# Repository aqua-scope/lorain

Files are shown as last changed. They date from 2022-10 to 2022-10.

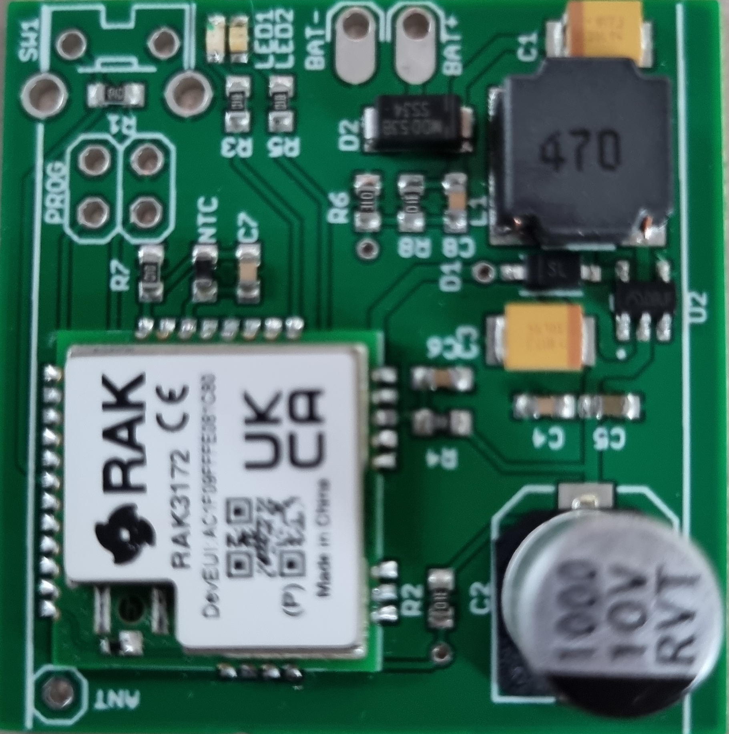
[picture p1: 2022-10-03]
img/lorain_pcba.jpg

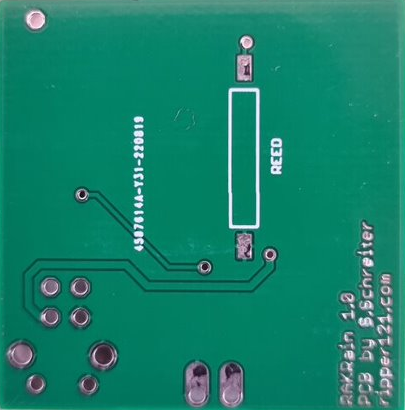
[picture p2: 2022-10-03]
img/lorain_pcb_back.png

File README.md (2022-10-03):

<h1> Lora Rain Sensor </h1>

<p>Lorain is an affordable LoraWAN rain sensor utilizing the RAK 3172 Lora Module that can be programmed using Arduino environment. </p>

<h2> Hardware</h2>

<p>There are multiple ways to acquire the hardware for the LoRain. The Aqua-Scope Webshop at <a href="https://shop.aqua-scope.com">shop.aqua-scope.com</a> offers different options depending on your willingness to spent own effort in exchange for money:
<ul>
<li>Complete product tested and ready to use</li>
<li>Kit with all needed components and need to solder some of the components and flash the firmware. 
The kit includes a PCBA almost fully populated</li>
<li>The plain enclosure of the device. You need to order the PCB / <a href="img/lorain_pcba.jpg">PCBA</a>, purchase and solder all components and flash the firmware. The 'How-To' below assumes this option.</li>
</ul>
<p> The folder /hardware contains the gerber data and Bill of material of the PCBs. You can order the PCB from one of the usual suspects for fast and cheap PCB manufacturing like jlcpcb or pcbway. Ordering own PCB and soldering all components requires a certain level of hardware knowledge and soldering skills. Hence, we don’t provide additional guidance beside offering the files for the PCB.
</p>

<h2>How to complete the LoRain Kit</h2>

<p>The LoRain Kit consists of the following components (see <a href="img/lorain_kit.png">image</a>):
<ul>
<li>enclosure including screws for mounting the enclosure to a flat surface, PCBA compartment and battery compartment</li>
<li>one screw to hold the battery compartment</li>
<li>2 * AA Batteries</li>
<li>CBA SMD complete</li>
<li>1 * 8.6 mm whip antenna</li>
<li>2 * wires to connect PCBA with battery compartment</li>
<li>Button</li>
<li>Reed contact</li>
</uL>
<p>The PCBA needs some soldering as shown in this (<a href="img/lorain_pcb_solder.png">image</a>). Please note that all soldering are done on the B-Sie that does not have any components. No soldering needed on A side with the components.
</p>
<ul>
<li>Connect the Battery + contact if the PCBA to the battery + contact of the battery compartment using the red wires</li>
<li>Connect the Battery - contact if the PCBA to the battery contact of the battery compartment using the black wires (<a href="img/lorain_pcb_solder.png">image</a>)</li>
<li>Insert the button into the hole of the PCB and solder it on the four pins</li>
<li>Solder the reed contact on the B-side as shown on the silk screen (<a href="img/lorain_pcb_back.png">image</a>)</li>
<li>Solder the whip antenna to the antenna tru-hole</li>
</ul> 

<h2> Firmware </h2>
  
<p>The firmware is written as Arduino Sketch using the RAK Wireless Arduino Environment. You need to install the Arduino IDE and follow the instructions of <a href="https://docs.rakwireless.com/Product-Categories/WisDuo/RAK3172-Module/Quickstart/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"> RAK wireless </a> to install the RAK board support package. </p>
  
<p>To flash a new firmware you need a simple USB-TTL-UART connector (<a href="https://www.amazon.de/AZDelivery-Konverter-kompatibel-Arduino-inklusive/dp/B089QJZ51Z/ref=asc_df_B089QJZ51Z"> e.g. this </a>). The firmware update mode on the RAK module is enabled using the AT command 'AT+BOOT' on the serial console of the Arduino IDE. </p>

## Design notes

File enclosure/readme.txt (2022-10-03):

looking for somebody willing to draw 3d model of the enclosure or even improve it.

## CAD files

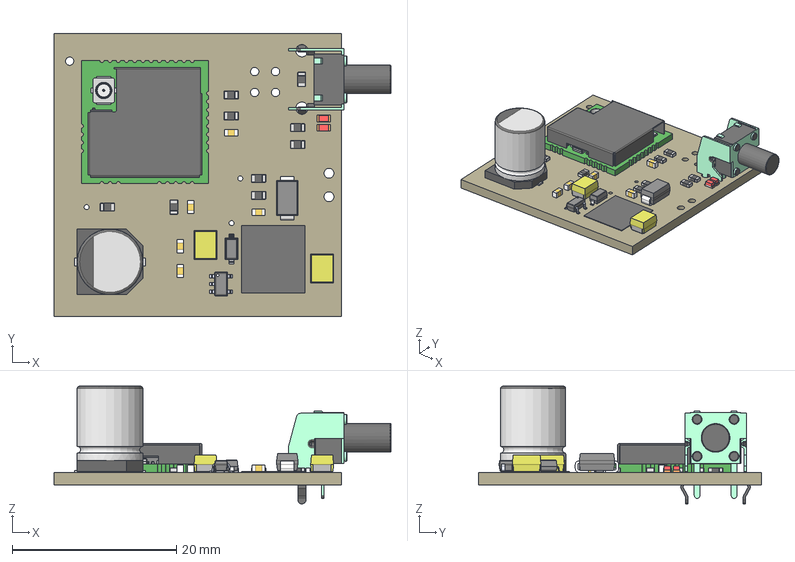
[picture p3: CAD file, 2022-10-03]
hardware/RainMeterRAK.step
41.1 x 34.5 x 14.4 mm
Board
SOD-123_MINI-SMA
140CLH-0810
SOD3715X145N
SOT23-5
0201_SMD_Capacitor x 36
Extruded
R0201 x 7
RES_1005-0402 x 3
QFN48_7x7
NT2016SA
C0402 x 4
crystal_rtf2012
D030A-屏蔽盖
SWPA8040S
SW_TACT_STANDARD_RIGHT_ANGLE
CHIP-LED0603 x 2
C0603 x 5
CT3528 x 2
R0603 x 9

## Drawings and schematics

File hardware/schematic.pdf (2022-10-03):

U2

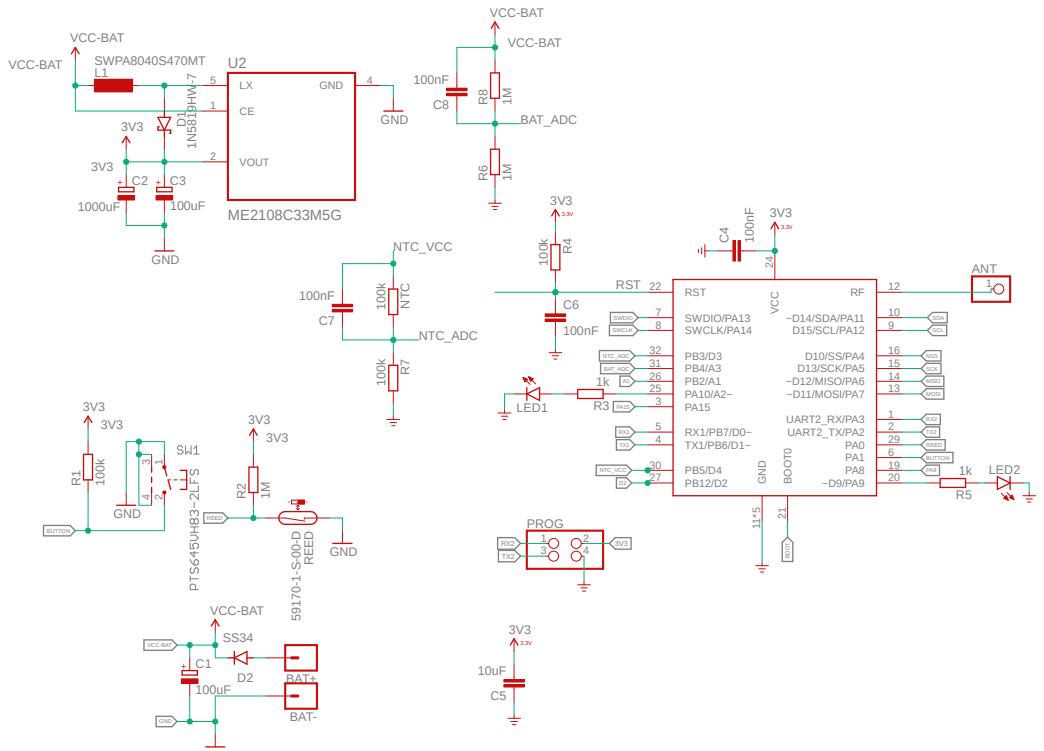
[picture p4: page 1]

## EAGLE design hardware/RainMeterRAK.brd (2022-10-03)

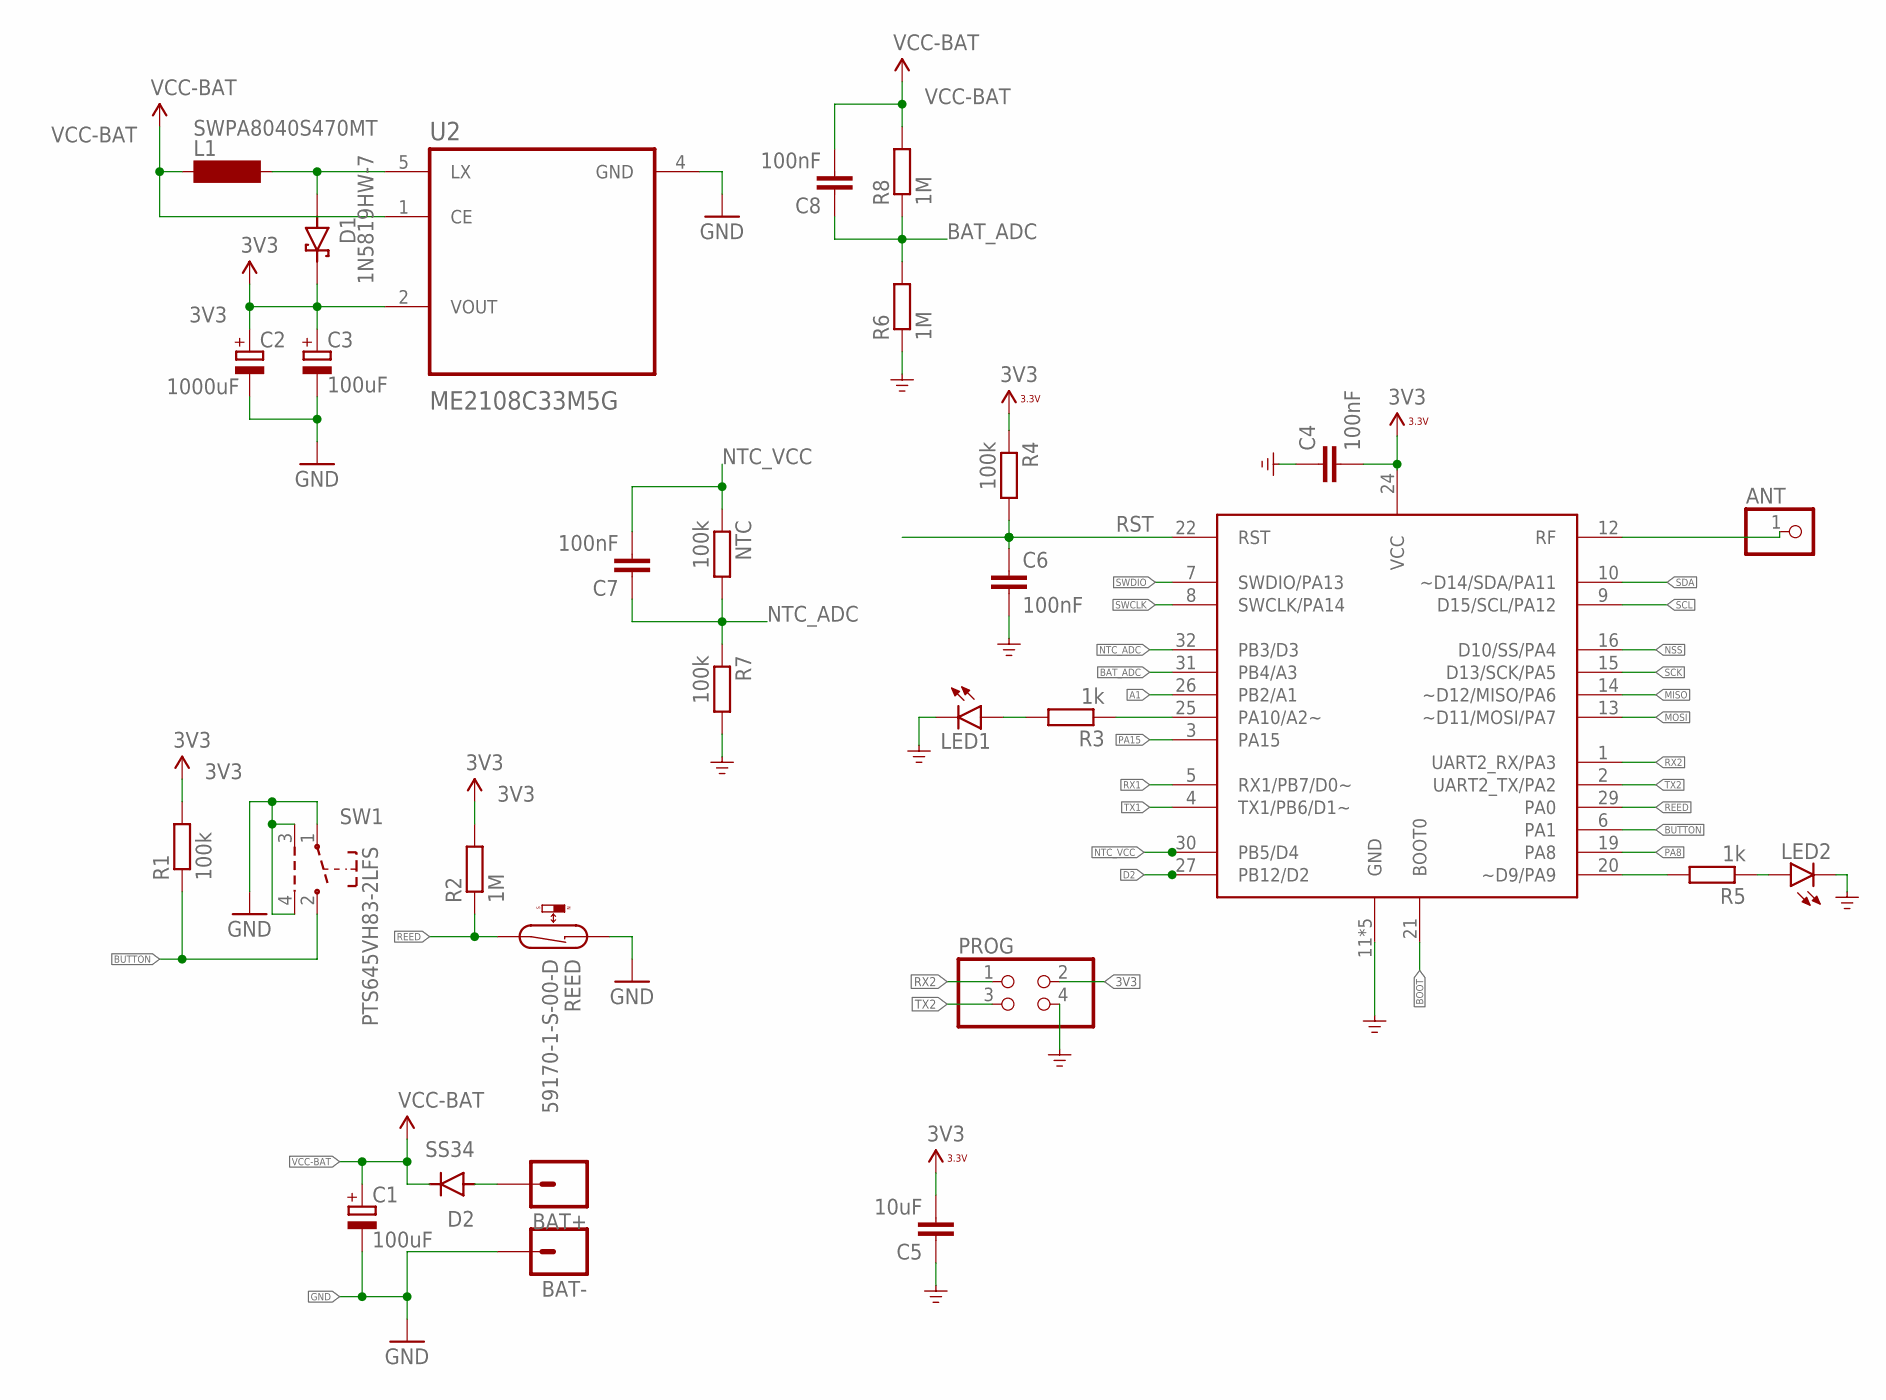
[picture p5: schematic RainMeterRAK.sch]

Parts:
ANT: PINHD-1X1; 1X01
BAT+: M01OFFSET; 1X01_OFFSET
BAT-: M01OFFSET; 1X01_OFFSET
C1, C3: 100uF; CT3528
C2: 1000uF; 140CLH-0810
C4, C6, C7, C8: 100nF; C0603
C5: 10uF; C0603
D1: 1N5819HW-7; SOD3715X145N
D2: SS34; SOD-123_MINI-SMA
L1: SWPA8040S470MT; SWPA8040S
LED1, LED2: LEDCHIP-LED0603; CHIP-LED0603
NTC: 100k; R0603
PROG: PINHD-2X2; 2X02
R1, R4, R7: 100k; R0603
R2, R6, R8: 1M; R0603
R3, R5: 1k; R0603
REED: 59170-1-S-00-D; CT10-G1
SW1: PTS645VH83-2LFS; SW_TACT_STANDARD_RIGHT_ANGLE
U1: RAK3172HF; RAK3172
U2: ME2108C33M5G; SOT23-5

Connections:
3V3: C2.+, C3.+, C4.2, C5.2, D1.C (K), PROG.2, R1.2, R2.2, R4.1, U1.24 (VCC), U2.2 (VOUT)
A1: U1.26 (PB2/A1)
BAT_ADC: C8.1, R6.2, R8.1, U1.31 (PB4/A3)
BOOT: U1.21 (BOOT0)
BUTTON: R1.1, SW1.2, U1.6 (PA1)
D2: U1.27 (PB12/D2)
GND: BAT-.1, C1.-, C2.-, C3.-, C4.1, C5.1, C6.2, LED1.C, LED2.C, PROG.4, R6.1, R7.2, REED.1, SW1.1, SW1.3, SW1.4, U1.11 (GND), U1.17 (GND), U1.18 (GND), U1.23 (GND), U1.28 (GND), U2.4 (GND)
MISO: U1.14 (~D12/MISO/PA6)
MOSI: U1.13 (~D11/MOSI/PA7)
unnamed: D1.A, L1.2, U2.5 (LX)
unnamed: R5.2, U1.20 (~D9/PA9)
unnamed: LED2.A, R5.1
unnamed: R3.1, U1.25 (PA10/A2~)
unnamed: LED1.A, R3.2
unnamed: ANT.1, U1.12 (RF)
unnamed: BAT+.1, D2.A
NSS: U1.16 (D10/SS/PA4)
NTC_ADC: C7.1, NTC.2, R7.1, U1.32 (PB3/D3)
NTC_VCC: C7.2, NTC.1, U1.30 (PB5/D4)
PA8: U1.19 (PA8)
PA15: U1.3 (PA15)
REED: R2.1, REED.2, U1.29 (PA0)
RST: C6.1, R4.2, U1.22 (RST)
RX1: U1.5 (RX1/PB7/D0~)
RX2: PROG.1, U1.1 (UART2_RX/PA3)
SCK: U1.15 (D13/SCK/PA5)
SCL: U1.9 (D15/SCL/PA12)
SDA: U1.10 (~D14/SDA/PA11)
SWCLK: U1.8 (SWCLK/PA14)
SWDIO: U1.7 (SWDIO/PA13)
TX1: U1.4 (TX1/PB6/D1~)
TX2: PROG.3, U1.2 (UART2_TX/PA2)
VCC-BAT: C1.+, C8.2, D2.C, L1.1, R8.2, U2.1 (CE)

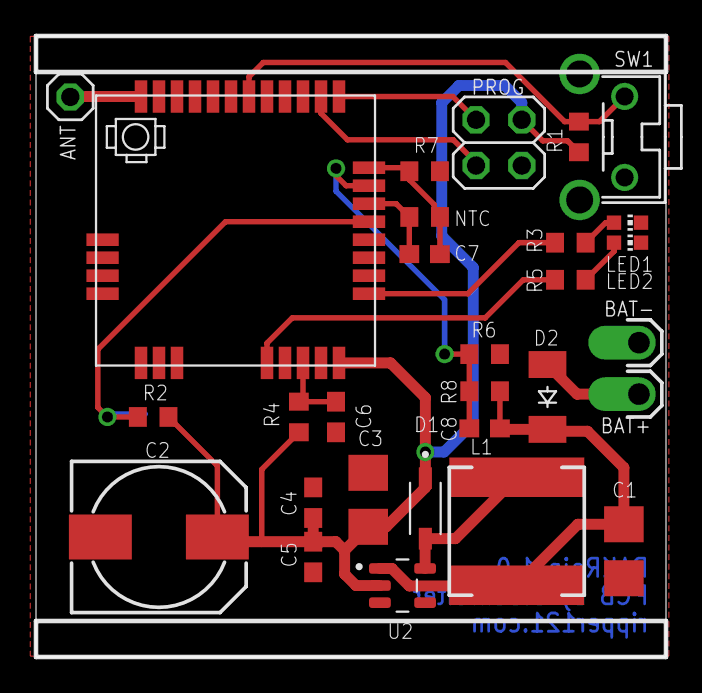
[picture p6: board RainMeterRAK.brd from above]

Board: 2 copper layers, 35.0 x 34.5 mm, 30 parts (1 on the bottom side), 18 nets.

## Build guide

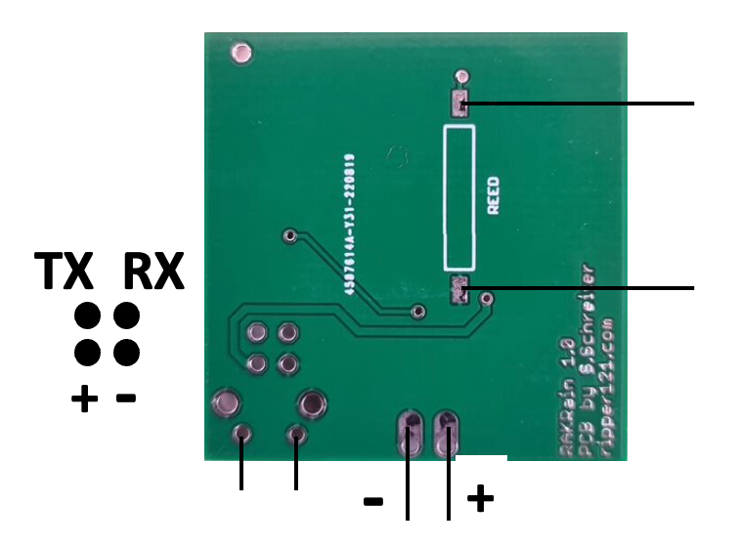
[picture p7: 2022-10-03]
img/lorain_pcb_solder.png

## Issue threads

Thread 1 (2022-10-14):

Battrie voltage measurement

hjoertel, 2022-10-14:
Batterie Voltage seems not to work.
I added serail print to see  what the analog(Read) delivers:
`voltage = analogRead(PIN_VOLTAGE);  // 4095 == 3,3V

Serial.printf("Voltage %d\n", voltage);

voltage = voltage/10*75/100;

Serial.printf("Voltage %d\n", voltage);`

After start up the result is:
  Voltage 72
  Voltage 5
and "5" is the value seen in the LoRa message, what is a strange value.
After 15 minutes, the batterie voltage is measured again :
  Voltage 81
  Voltage 6
after that, the following measures are all the same.

christianpaetz, 2022-10-14:
thanks for debugging. Do you run it on battery while connected to USB/UART or do you use the UART power?

hjoertel, 2022-10-14:
Am Freitag, 14. Oktober 2022, 18:04:45 CEST schrieb christianpaetz:
> thanks for debugging. Do you run it on battery while connected to USB/UART or do you use the UART power?

Can that be the reason? I can only debug when the module is connected vie the USB->TTL powered with 3,3 V and outside of the Rain housing.

Now, with running in the housing, from the TTN console I get

"decoded_payload": {
        "bat_consumption": 0,
        "bat_voltage": 32,
        "capabilities": 1,
        "fw_version": 221014,
        "hw_version": 5,
        "rainlevel": 1,
        "temperature": 220,
        "uptime": 0
      },

Does that mean the value is correct and "32" means 3,2 V ?

Heinz

christianpaetz, 2022-10-14:
yes, accd. to manual value is in 100 mV steps, hence the 32 is correct. Please note that the board as an additional power converter and battery is measured before the converter while the UART is connected after the converter

Closed 2022-10-14.

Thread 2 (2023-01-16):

Sensor hangs up without comment and stops the heartbeat.

DasNordlicht, 2023-01-16:
After about 4-5 weeks, the sensor hangs up without comment and stops the heartbeat.
The sensor is set to a heartbeat time of one hour.
Is anything known about this?
I will try to restart the sensor, a first attempt with the button failed and it does not come up.

FR-ADDIX, 2023-01-17:
The first device reconnected without a problem after I drained the capacitor.
The second device always reports: "DevNonce is too small" when restarting.

`{
  "name": "ns.up.join.cluster.fail",
  "time": "2023-01-17T06:18:43.280202514Z",
  "identifiers": [
    {
      "device_ids": {
        "device_id": "eui-06000010006ff4f1",
        "application_ids": {
          "application_id": "lorain-nucleon"
        },
        "dev_eui": "06000010006FF4F1",
        "join_eui": "4943485448592021",
        "dev_addr": "260BF68A"
      }
    }
  ],
  "data": {
    "@type": "type.googleapis.com/ttn.lorawan.v3.ErrorDetails",
    "namespace": "pkg/joinserver",
    "name": "dev_nonce_too_small",
    "message_format": "DevNonce is too small",
    "correlation_id": "1c5d6d3ee10a4cc7a6e15e715a54247d",
    "code": 3
  },
  "correlation_ids": [
    "gs:conn:01GPSXRQ0R5HYD3YB31XZGGKMC",
    "gs:up:host:01GPSXRQ11ATEYG7D0Z7N6V4WX",
    "gs:uplink:01GPZ62GP9RH1EPB0PS4PFRZN5",
    "ns:uplink:01GPZ62GPAN0PKJ6CSAZY8JKTT",
    "rpc:/ttn.lorawan.v3.GsNs/HandleUplink:01GPZ62GPA1475SBKERYV13NN5"
  ],
  "origin": "ip-10-100-14-36.eu-west-1.compute.internal",
  "context": {
    "tenant-id": "CgN0dG4="
  },
  "visibility": {
    "rights": [
      "RIGHT_APPLICATION_TRAFFIC_READ"
    ]
  },
  "unique_id": "01GPZ62GPG2JBS84N5VXPNSNB4"
}`

aqua-scope, 2023-01-17:
for (1). Good point. We changed the manual on the point (https://www.aqua-scope.com/down/RANLWE01UniManual11.pdf) to ensure that cap is discharged before new batteries are inserted. This is a double-sided sword. Having two step-up converters in line( internal by STM32 from 2.2 -> 3.0 V plus external from 1.2 V -> 3V) is extra cost and causes the cap problem, on the other hand we only have 2 * AAA is outdoor conditions so the extra Volt is valuable.

(2) This is strange, never seen this and the Application code can not influence the DevNounce. Do you have access to the Gateway logging in TTN to see the nounce used ?

FR-ADDIX, 2023-01-17:
(1) thx

(2) Yes, I have access to the GW logs, but of course I did not make a copy of the data when the error occurred. I would have to trigger the error again, but it only occurs sporadically at startup.
Next weekend I can deal with it and provoke an error.

FR-ADDIX, 2023-01-17:
But the general question is why do 3 sensors go out within a few hours of each other and refuse to work ?
I looked again, the sensors were all activated around 21.12.2022. they are all 3 within a time span of about 12 hours on 16.01.2023 deceased.
The batteries all have over 2.8 volts

aqua-scope, 2023-01-18:
Hello Frank, can you please checked your linkedin-account. I sent a private message

ukrope, 2023-01-26:
one sensor send once and then stops:
{
  "name": "as.up.data.forward",
  "time": "2023-01-25T11:14:49.586327607Z",
  "identifiers": [
    {
      "device_ids": {
        "device_id": "eui-06000015a3577305",
        "application_ids": {
          "application_id": "uregensensor"
        },
        "dev_eui": "06000015A3577305",
        "join_eui": "4943485448592021",
        "dev_addr": "260B053C"
      }
    }
  ],
  "data": {
    "@type": "type.googleapis.com/ttn.lorawan.v3.ApplicationUp",
    "end_device_ids": {
      "device_id": "eui-06000015a3577305",
      "application_ids": {
        "application_id": "uregensensor"
      },
      "dev_eui": "06000015A3577305",
      "join_eui": "4943485448592021",
      "dev_addr": "260B053C"
    },
    "correlation_ids": [
      "as:up:01GQMA6EKBKF875XMAJMM66W14",
      "gs:conn:01GQ2ZAG79FK6PAC46SDE46KHY",
      "gs:up:host:01GQ2ZAG7HGM96E6XSW2265DBY",
      "gs:uplink:01GQMA6ECXH2VPRAPFBGAXA6KZ",
      "ns:uplink:01GQMA6ECY3YCZA7C7J9J1CJNY",
      "rpc:/ttn.lorawan.v3.GsNs/HandleUplink:01GQMA6ECYFDPB1AACY86D0568",
      "rpc:/ttn.lorawan.v3.NsAs/HandleUplink:01GQMA6EKBWMT4YEVHDK4G7M81"
    ],
    "received_at": "2023-01-25T11:14:49.579441405Z",
    "uplink_message": {
      "session_key_id": "AYXoov7dezMyehAgdFYncg==",
      "f_port": 10,
      "f_cnt": 1,
      "frm_payload": "CgADgt4DAQABCwEDRT8=",
      "decoded_payload": {
        "alarm_status": 1,
        "alarm_type": 3,
        "alarm_value": 17727,
        "capabilities": 1,
        "fw_version": 230110,
        "hw_version": 1
      },
      "rx_metadata": [
        {
          "gateway_ids": {
            "gateway_id": "wlanfr3ak-dl9fhx-db0il",
            "eui": "3135323519005D00"
          },
          "time": "2023-01-25T11:14:49.324017Z",
          "timestamp": 1054129284,
          "rssi": -102,
          "channel_rssi": -102,
          "snr": 4.5,
          "location": {
            "latitude": 54.309544,
            "longitude": 10.169995,
            "altitude": 50,
            "source": "SOURCE_REGISTRY"
          },
          "uplink_token": "CiQKIgoWd2xhbmZyM2FrLWRsOWZoeC1kYjBpbBIIMTUyNRkAXQAQhPnS9gMaDAipnsSeBhDT94OyASCgx4H41oaFAQ==",
          "received_at": "2023-01-25T11:14:49.355732074Z"
        },
        {
          "gateway_ids": {
            "gateway_id": "ki-tn-gw-wap-lora8",
            "eui": "3133303725005100"
          },
          "time": "2023-01-25T11:14:34.314682Z",
          "timestamp": 843362020,
          "rssi": -111,
          "channel_rssi": -111,
          "snr": 0.75,
          "location": {
            "latitude": 54.29950992259645,
            "longitude": 10.179337263107302,
            "altitude": 60,
            "source": "SOURCE_REGISTRY"
          },
          "uplink_token": "CiAKHgoSa2ktdG4tZ3ctd2FwLWxvcmE4EggxMzA3JQBRABDk3ZKSAxoMCKmexJ4GEKGNk7YBIKDVrOLFhgY=",
          "received_at": "2023-01-25T11:14:49.359660108Z"
        },
        {
          "gateway_ids": {
            "gateway_id": "ukv3",
            "eui": "58A0CBFFFE801327"
          },
          "time": "2023-01-25T11:14:49.326077938Z",
          "timestamp": 2083405500,
          "rssi": -21,
          "channel_rssi": -21,
          "snr": 7.5,
          "location": {
            "latitude": 54.298395486446545,
            "longitude": 10.172197222709656,
            "source": "SOURCE_REGISTRY"
          },
          "uplink_token": "ChIKEAoEdWt2MxIIWKDL//6AEycQvP244QcaDAipnsSeBhCS+dm7ASDgnJSl0bMD",
          "received_at": "2023-01-25T11:14:49.354618806Z"
        },
        {
          "gateway_ids": {
            "gateway_id": "eui-7076ff0056050d13",
            "eui": "7076FF0056050D13"
          },
          "time": "2023-01-25T11:14:49.321Z",
          "timestamp": 3595158164,
          "rssi": -122,
          "channel_rssi": -122,
          "snr": -10.2,
          "location": {
            "latitude": 54.417325,
            "longitude": 10.1718515,
            "altitude": 40,
            "source": "SOURCE_REGISTRY"
          },
          "uplink_token": "CiIKIAoUZXVpLTcwNzZmZjAwNTYwNTBkMTMSCHB2/wBWBQ0TEJSFp7INGgwIqZ7EngYQsf7svgEgoKSAgdGLnAEqDAipnsSeBhDApIiZAQ==",
          "channel_index": 5,
          "gps_time": "2023-01-25T11:14:49.321Z",
          "received_at": "2023-01-25T11:14:47.187369037Z"
        },
        {
          "gateway_ids": {
            "gateway_id": "0000024b0b03229f",
            "eui": "0000024B0B03229F"
          },
          "timestamp": 1719259604,
          "rssi": -102,
          "channel_rssi": -102,
          "snr": 5.5,
          "uplink_token": "Ch4KHAoQMDAwMDAyNGIwYjAzMjI5ZhIIAAACSwsDIp8Q1KPnswYaDAipnsSeBhCgl/f2ASCgyO7ehNKcAQ==",
          "channel_index": 5,
          "received_at": "2023-01-25T11:14:49.517852064Z"
        },
        {
          "gateway_ids": {
            "gateway_id": "0000024b0b031fa7",
            "eui": "0000024B0B031FA7"
          },
          "timestamp": 1603909412,
          "rssi": -120,
          "channel_rssi": -120,
          "snr": -15,
          "location": {
            "latitude": 54.34101717,
            "longitude": 10.18077217,
            "altitude": 63,
            "source": "SOURCE_REGISTRY"
          },
          "uplink_token": "Ch4KHAoQMDAwMDAyNGIwYjAzMWZhNxIIAAACSwsDH6cQpO7m/AUaDAipnsSeBhCWi7qKAiCgyc2D186cAQ==",
          "channel_index": 5,
          "received_at": "2023-01-25T11:14:49.558794134Z"
        }
      ],
      "settings": {
        "data_rate": {
          "lora": {
            "bandwidth": 125000,
            "spreading_factor": 12,
            "coding_rate": "4/5"
          }
        },
        "frequency": "868100000",
        "timestamp": 1054129284,
        "time": "2023-01-25T11:14:49.324017Z"
      },
      "received_at": "2023-01-25T11:14:49.374387698Z",
      "consumed_airtime": "1.646592s",
      "network_ids": {
        "net_id": "000013",
        "tenant_id": "ttn",
        "cluster_id": "eu1",
        "cluster_address": "eu1.cloud.thethings.network"
      }
    }
  },
  "correlation_ids": [
    "as:up:01GQMA6EKBKF875XMAJMM66W14",
    "gs:conn:01GQ2ZAG79FK6PAC46SDE46KHY",
    "gs:up:host:01GQ2ZAG7HGM96E6XSW2265DBY",
    "gs:uplink:01GQMA6ECXH2VPRAPFBGAXA6KZ",
    "ns:uplink:01GQMA6ECY3YCZA7C7J9J1CJNY",
    "rpc:/ttn.lorawan.v3.GsNs/HandleUplink:01GQMA6ECYFDPB1AACY86D0568",
    "rpc:/ttn.lorawan.v3.NsAs/HandleUplink:01GQMA6EKBWMT4YEVHDK4G7M81"
  ],
  "origin": "ip-10-100-15-91.eu-west-1.compute.internal",
  "context": {
    "tenant-id": "CgN0dG4="
  },
  "visibility": {
    "rights": [
      "RIGHT_APPLICATION_TRAFFIC_READ"
    ]
  },
  "unique_id": "01GQMA6EKJE0J1J88W591F93PT"
}
battery out, battery in, new start, same :
{
  "name": "as.up.data.forward",
  "time": "2023-01-26T09:25:44.891272077Z",
  "identifiers": [
    {
      "device_ids": {
        "device_id": "eui-06000015a3577305",
        "application_ids": {
          "application_id": "uregensensor"
        },
        "dev_eui": "06000015A3577305",
        "join_eui": "4943485448592021",
        "dev_addr": "260BE9B2"
      }
    }
  ],
  "data": {
    "@type": "type.googleapis.com/ttn.lorawan.v3.ApplicationUp",
    "end_device_ids": {
      "device_id": "eui-06000015a3577305",
      "application_ids": {
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
ukrope, 2023-01-26:
problems with two  complete device sensors, one does not have contact, the other one starts, send once data and then stops, after starting the battery same results.

rcmcronny, 2023-06-25:
Have one sensor, "dead" after ~27 days uptime.
Remove batteries push button 20 seconds, reinsert batteries and now it works again.

Also the alarm status gets send but is not resetet (remains on "1")

aqua-scope, 2023-06-25:
The problem is well described in the RAK Wireless forum (https://forum.rakwireless.com/t/rak3172-does-not-respond-to-at-commands-after-48-days/9315/43). It's a (buffer overflow) bug in their library up to 4.0.2. The solution is to recompile your code using SDK 4.0.3 of RAK Wireless 3172 lib.

rcmcronny, 2023-06-25:
I use SDK 4.0.5 so this mentioned buffer overflow bug is fixed in this.

aqua-scope, 2023-06-26:
You wrote the device works again. Can we heck if it stops again in 27 days? I am not aware of such an error. All devices < 4.03 has the error described in the RAk forum, the first devices just reached the 48 day limit and survived. Your error description clearly shows a hanger in the firmware, since reboot works. Would be cool to know if the serial console still works.

rcmcronny, 2023-06-26:
Yeahh, uptime is 2 days, so i will report, if it repeats at ~ 27 days again. And of course i will attach a serial to check then.

rcmcronny, 2023-08-01:
Ok so now are 37 days gone and working. this is sus, but better than catching bugs.  Sorry for bothering. I will have an eye on the uptime and see, what happens on day 48.

rcmcronny, 2024-05-30:
seems to work, 49 days, then it starts with 0 days and ongoing. for me this is ok so

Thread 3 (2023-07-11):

Open Source License

michael-gollan, 2023-07-11:
Hi,

We might utilize the sensor in a citizen science project. However, it is required for this purpose that it is open source and has a license.

Could you please add an open source license (e.g., GPL or EUPL 1.2 https://joinup.ec.europa.eu/sites/default/files/custom-page/attachment/2020-03/EUPL-1.2%20EN.txt) file to the root directory?

Best regards

aqua-scope, 2023-07-11:
done

Closed 2023-07-11.

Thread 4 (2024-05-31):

What are the units / data types of the parsed values?

SeppPenner, 2024-05-31:
What are the units and / or data types of the values in the parser under https://github.com/aqua-scope/lorain/blob/main/rain_ttn_decoder.js?

E.g. see the table below. It would be nice if I could get it filled out properly.

|Parameter|Size|Data type|Example value|Description|
|--|--|--|--|--|
|`hw_version`|1 Byte|uint8?|1|Hardware version as integer?|
|`capabilities`|2 Bytes|uint16?|?|?|
|`conf_heartbeat`|2 Bytes|uint16?|20s|Heartbeat interval in seconds?|
|`conf_heavyrain`|2 Bytes|uint16?|?|?|
|`conf_interval`|2 Bytes|uint16?|5s|Configurations interval in seconds?|
|`temperature`|2 Bytes|uint16?|5°C|Temperature in °C?|
|`uptime`|2 Bytes|uint16?|20s|Uptime in seconds?|
|`rainlevel`|2 Bytes|uint16?|?|Rain level on a certain scale (e.g. `hardness`)?|
|`fw_version`|4 Bytes|4 uint8? in the form 1.2.3.4|1.2.3.4|Firmware version in the form 1.2.3.4?|
|`alarm_status`|1 Byte|uint8?|?|?|
|`alarm_type`|1 Byte|uint8?|?|?|
|`alarm_value`|2 Bytes|uint16?|?|?|
|`bat_voltage`|1 Byte|uint8?|20V|Battery voltage in volts?|
|`bat_consumption`|2 Bytes|uint16?|20%|Battery consumption in percentage?|

ohobby, 2024-09-27:
The LoRain PDF contains the following, which helps with some values.

Communication Protocol
The device can be controlled directly via LoRaWAN. For this purpose, different commands are defined, which are used either 'uplink’, i.e. from the device to the LoRa network, or 'downlink’, i.e. from the LoRa network to the device. Commands can be cascaded up to the maximum number of 52 bytes. All values of the command descriptions are bytes, unless otherwise specified.
Downlink-Commands (using FPort 2):
• 0x03: Get hardware ID, device answers with uplink command 0x03
• 0x04 PP VV_MSB VV_LSB: Set configuration parameter PP for new 16 Bit value VV
• 0x1a: Get firmware version, device answers with uplink command 0x03a
• 0x14 PP: Get configuration parameter PP, device answers with uplink command 0x04
Uplink-Commands (using FPort 2):
• 0x03 XX YY_MSB, YY_LSB: Report hardware version XX and device capabilities bitmap YY
• 0x04 PP VV_MSB VV_LSB: Report 16 Bit Value VV of configuration parameter PP
• 0x06 YY VV_MSB VV_LSB: Report 16 Bit Sensor Value
• YY=0x01: Temperature in 1 degree Celsius. Please note, the temp sensor is based on NTC + resistor and not calibrated. Its only a rough estimate of temperature.
• YY=0x03: Uptime in hours
• YY=0x82: Rain level in measurement steps of 0,5 mm water level.
• 0x0a YY_MSB YY YY YY_LSB: Report firmware version as 32 Bit value
• 0x0b XX YY ZZ_MSB, ZZ_LSB: Report alarm state XX (1 or 0) of alarm type YY with optional value Z. Current alarm types are
• XX=0x03: sensor alarm (Z is seconds between two events:0.5 mm within Z s.),
• XX=0x0c: battery alarm
• 0x12 XX YY_MSB, YY_LSB: Battery status, XX = voltage in 100 mV, YY Consumption since reboot in mAh
Configuration Parameters
Parameter 2 – Heartbeat Interval
Description: This parameter defines after how many measurement intervals the sensor will send a report regardless of rainfall. The factory default is 24 which translates together with the default value of parameter #1 (900 seconds = 15 minutes) into 24 * 15 minutes = 6 hours.
Parameter 3 – Heavy Rain Threshold
Description: This parameter defines the heavy rain level as time interval (in seconds) for 0.5 mm rain. The default value of 120 means that 0.5 in 120 seconds or less will cause heavy rain alarm. This translates into 15 liter/h.
Parameter 4 – Measurement Interval in Seconds
Description: In case of rain the device reports regularly to the LORA network. This parameter defines the time interval for these reports in seconds. The default is 900 = 15 minutes. The value range is 10 – 60000.

SeppPenner, 2024-10-22:
So, this gives for me (Assuming that all values are `uintxy`, not `intxy`:

|Parameter|Size|Data type|Example value|Description|
|--|--|--|--|--|
|`hw_version`|1 Byte|uint8|1|Hardware version as integer?|
|`capabilities`|2 Bytes|uint16|?|?|
|`conf_heartbeat`|2 Bytes|uint16|20 => 20 * 15 = 300 minutes|Heartbeat interval in minutes --> 15 minutes per step ✅|
|`conf_heavyrain`|2 Bytes|uint16|10 => 0,5mm / 10 seconds|Heavy rain threshold in seconds, means 0,5mm / n seconds ✅|
|`conf_interval`|2 Bytes|uint16|5s|Configurations interval in seconds ✅|
|`temperature`|2 Bytes|uint16|5°C|Temperature in °C✅|
|`uptime`|2 Bytes|uint16|20h|Uptime in hours✅|
|`rainlevel`|2 Bytes|uint16|4 => 2mm|Rain level on a certain scale (e.g. `hardness`) --> 0,5mm per step ✅|
|`fw_version`|4 Bytes|4 uint8 in the form 1.2.3.4|1.2.3.4|Firmware version in the form 1.2.3.4?|
|`alarm_status`|1 Byte|uint8|?|?|
|`alarm_type`|1 Byte|uint8|?|?|
|`alarm_value`|2 Bytes|uint16|?|?|
|`bat_voltage`|1 Byte|uint8|20 => 20 * 100 = 2000 mV|Battery voltage in 100 mV✅|
|`bat_consumption`|2 Bytes|uint16|20 => 20mAh|Battery consumption sinc the last reboot in mAh✅|

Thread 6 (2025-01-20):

3d model - how does it tip over?

cyclops1982, 2025-01-20:
Hi,

I've been looking at this device and i'm quite interested in it for multiple reasons. I'm happy to draw some FreeCad models for this to provide that.

However, i'm not sure how the device works - i don't see any moving parts and as far as i understand, it flips over. So how does that work?

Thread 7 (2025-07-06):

Device configuration

desvalets, 2025-07-06:
I recently purchased a pre-assembled Lorain device and connected it to a private Lorawan gateway and Chirpstack setup. This setup works well.  However, the range is a bit short.  I receive uplink events from the Lorain when it is about 60 m from the gateway antenna, but not much further. Is there a way to upgrade range by adding an antenna ?  Also the codec script contains coding to get the temperature but this number never changes on the uplinked data  so I wonder if the device has a temperature sensor ?  Or maybe I am not understanding something ?

christianpaetz, 2025-07-08:
The antenna is a simple pigtail but tuned to the 868 MHz, This big disadvantage is that due to the enclosure design the antenna is near the bottom of the device, if you mount this away from ground you will get substantially better range. There is a temperature sensor but its not much more than a test sensor. Its inside the inner plasci enclosure which is inside the outer plastic enclosure and the dark grey makes sure that sun light will heat it up. Its place on the board. but don't use it for real. If you really want to play with it, you can write your own sketch.

desvalets, 2025-07-08:
#response_container_BBPPID{font-family: initial; font-size:initial; color: initial;}  Hi Thanks for your reply. I think my device is too close to the ground so I'll test again on a higher mast. Best regards                                                                                                                                                                           De: ***@***.***é: 8 juillet 2025 14:23À: ***@***.***épondre à: ***@***.***: ***@***.***; ***@***.***: Re: [aqua-scope/lorain] Device configuration (Issue #7)  christianpaetz left a comment (aqua-scope/lorain#7)
The antenna is a simple pigtail but tuned to the 868 MHz, This big disadvantage is that due to the enclosure design the antenna is near the bottom of the device, if you mount this away from ground you will get substantially better range. There is a temperature sensor but its not much more than a test sensor. Its inside the inner plasci enclosure which is inside the outer plastic enclosure and the dark grey makes sure that sun light will heat it up. Its place on the board. but don't use it for real. If you really want to play with it, you can write your own sketch.

—Reply to this email directly, view it on GitHub, or unsubscribe.You are receiving this because you authored the thread.Message ID: ***@***.***>

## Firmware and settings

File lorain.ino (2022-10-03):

#define PIN_REED    0x00
#define PIN_BUTTON  0x01
#define PIN_LEDR    0x0A
#define PIN_LEDG    0x09
#define PIN_NTC     PB3
#define PIN_NTC_VCC PB5
#define PIN_VOLTAGE PB4

#define LED_ON  HIGH
#define LED_OFF LOW
#define BUTTON_ON LOW
#define BUTTON_OFF HIGH

#define CONFIGSIZE 8
#define DEFAULT_INTERVAL  900 // 15 min
#define DEFAULT_HEARTBEAT 4 // 1h
#define DEFAULT_HEAVYRAIN 120 // 1 flip every 120 s => 30 f/h = 15 l/h

#define OTAA_DEVEUI   {0x01, 0x02, 0x03, 0x04, 0x05, 0x06, 0x07, 0x08}
#define OTAA_APPEUI   {0x0E, 0x0D, 0x0D, 0x01, 0x0E, 0x01, 0x02, 0x0E}
#define OTAA_APPKEY   {0x2B, 0x7E, 0x15, 0x16, 0x28, 0xAE, 0xD2, 0xA6, 0xAB, 0xF7, 0x15, 0x88, 0x09, 0xCF, 0x4F, 0x3E}
 
bool                isLoRaWAN     =  false;
const char          compileDate[] = __DATE__ " " __TIME__;
const uint8_t       hwVersion = 0x05;
bool                heavyRain = false;
volatile uint16_t   flipCount = 0;
volatile bool       flipState = false;
uint32_t            lastFlip = 0;
uint32_t            confirmcount = 0;
uint16_t            uAs;
float               temperature;
uint16_t            voltage;
uint32_t            configs[CONFIGSIZE];
int                 heartbeat = 0;
bool                rx_done = false;

int switchMode(SERIAL_PORT port, char *cmd, stParam *param) {
  if (param->argc == 1) {     
    uint32_t mode = strtoul(param->argv[0],NULL,10);
    configs[7] = mode?0:1;
    writeConfigFlash();
    Serial.printf("Switch over to %s-Mode\n",mode?"LoRaWAN":"P2P");
    api.lorawan.nwm.set(mode); 
    writeConfigFlash();
  } else {
  return AT_PARAM_ERROR;
  }
  return AT_OK;
}

int defaultReset(SERIAL_PORT port, char *cmd, stParam *param) {
  Serial.println("Reset to Default");
  api.system.restoreDefault();
  return AT_OK;  
}

int setSerial(SERIAL_PORT port, char *cmd, stParam *param) {
  if (param->argc == 1) {     
    configs[6] = strtoul(param->argv[0],NULL,16);
    Serial.printf("Serial Number is 0x%04x\n",configs[6]);
  } else {
    return AT_PARAM_ERROR;
  }
  return AT_OK;
}

int cmdConfig(SERIAL_PORT port, char *cmd, stParam *param) {
    if (param->argc == 1 && !strcmp(param->argv[0], "?")) {
        Serial.printf("Configs %04x %04x %04x %04x %04x\n",configs[0],configs[1],configs[2],configs[3],configs[4]);
    } else if (param->argc == 1) {     
        String pv = String(param->argv[0]); 
        uint8_t p = strtoul(pv.substring(0,1).c_str(), NULL, 16);
        uint32_t v = strtoul(pv.substring(2).c_str(), NULL, 16);       
        configs[p]=v;
        Serial.printf("config %d:%04x\n",p,v);
        writeConfigFlash();
    } else {
        return AT_PARAM_ERROR;
    }
    return AT_OK;
}

void flip() { 
  uint32_t diff = millis() - lastFlip;
  if (diff < 4000) return;
  flipCount++;   
  if ((diff/1000) < configs[3] && !heavyRain) {
    heavyRain = true;
    Serial.println("HR Alarm Set");
    sendHeavyRainAlarm(true,diff);
  }
  else if ((diff/1000) > configs[3] && heavyRain) {
    sendHeavyRainAlarm(false,diff); 
    Serial.println("HR Alarm Cleared");
    heavyRain = false;      
  }   
  lastFlip = millis();    
  delay(200);
  uAs ++; // *0,1 mAs; (8000uA * 16 ms)
}

void buttonpress() { 
  detachInterrupt(PIN_BUTTON);  
  digitalWrite(PIN_LEDR, LED_ON); 
  Serial.println("button pressed");
  delay(1000);
  if(digitalRead(PIN_BUTTON) == BUTTON_ON && !api.lorawan.nwm.get()) {
    Serial.printf("Try LoRaWAN again: %s\r\n", api.lorawan.nwm.set(1) ? "Success" : "Fail");
  }
  if (isLoRaWAN) {
    sendHeartBeat();
    lorawanSend();
  }
  //delay(200);
  digitalWrite(PIN_LEDR, LED_OFF);
  attachInterrupt(PIN_BUTTON, buttonpress, BUTTON_ON);    
}

void signal(bool state) {
  digitalWrite(PIN_LEDR, LED_OFF);
  digitalWrite(PIN_LEDG, LED_OFF);
  for (int i=0;i<4;i++) {
    digitalWrite(state?PIN_LEDG:PIN_LEDR, LED_ON);
    api.system.sleep.all(50);
    digitalWrite(state?PIN_LEDG:PIN_LEDR, LED_OFF);
    api.system.sleep.all(200);
    }  
  digitalWrite(state?PIN_LEDG:PIN_LEDR, LED_OFF);   
  }

void setup() {
  Serial.begin(115200);
  Serial.printf("RAK Firmware Version: %s\r\n", api.system.firmwareVersion.get().c_str());
  pinMode(PIN_LEDG, OUTPUT);
  pinMode(PIN_LEDR, OUTPUT);
  pinMode(PIN_NTC_VCC, OUTPUT); 
  pinMode(PIN_NTC, INPUT);  
  pinMode(PIN_BUTTON, INPUT);  
  pinMode(PIN_VOLTAGE, INPUT);    
  pinMode(PIN_REED, INPUT);
  //analogReference(RAK_ADC_MODE_3_0);   
  if (api.lorawan.nwm.get()) { // LoRaWAN Mode
    digitalWrite(PIN_LEDG, LED_ON);
    digitalWrite(PIN_LEDR, LED_ON); 
    }
  api.system.atMode.add((char *)"CONFIG", (char *)"Get/Set Config Values", (char *)"CONFIG", cmdConfig, RAK_ATCMD_PERM_WRITE | RAK_ATCMD_PERM_READ); 
  api.system.atMode.add((char *)"RESET", (char *)"Factory Defaults", (char *)"RESET", defaultReset, RAK_ATCMD_PERM_WRITE | RAK_ATCMD_PERM_READ); 
  api.system.atMode.add((char *)"MODE", (char *)"Changes Lora Mode", (char *)"MODE", switchMode, RAK_ATCMD_PERM_WRITE | RAK_ATCMD_PERM_READ);                         
  delay(3000); // emergency stop to input boot mode command
  readConfigFlash(); 
  loraSetup();
  attachInterrupt(PIN_REED, flip, FALLING);
  attachInterrupt(PIN_BUTTON, buttonpress, BUTTON_ON);  
  uAs = 1230; // *0.1 mAs setup 1,3 s @95 mA
}

void loop() {
  uint32_t diff = millis()/1000 - lastFlip;
  Serial.printf("Wakeup: time=%d flips=%d, count=%d,last=%d reed %d\n",millis()/1000,flipCount,heartbeat,lastFlip,digitalRead(PIN_REED));
  digitalWrite(PIN_NTC_VCC, HIGH); 
  delay(200);
  float r_ntc = (float)(configs[5] * 1000) * (1023.0/((float)analogRead(PIN_NTC))-1.0); // R7 is 100 kOhm    
  temperature  = (1 / ((log(r_ntc / 100000.0) / 4485.0) + (1.0 / (25.0 + 273.15))))- 273.15; 
  // NTCG164KF104FT1: b=4485/ r=100KOhm @ 25 Degree  
  voltage = analogRead(PIN_VOLTAGE)/10*75/100;
  digitalWrite(PIN_NTC_VCC, LOW);    
  uAs += configs[4] * 6/100; // * 0,1 mAs;
  if (++heartbeat >= configs[2] || flipCount || (heavyRain && diff > configs[3])) {
    confirmcount ++;
    uAs +=  57; // * 0,1 mAs (60 ms @ 95 mA)
    sendHeartBeat( );
    if (flipCount) flipCount=0; else heartbeat = 0;
    if (heavyRain && diff > configs[3]) {
      loraAddByteToBuffer(0x0b);
      loraAddByteToBuffer(0);  
      loraAddByteToBuffer(0x03);    
      loraAddWordToBuffer(0);
      heavyRain = false;       
    }
    if(isLoRaWAN) {
      if(confirmcount > 10) { // every 10th paket is confirmed to check join status
        api.lorawan.cfm.set(true); 
        confirmcount=0;     
      }
      else
        api.lorawan.cfm.set(false);
        lorawanSend();
    } 
  } 
  api.system.sleep.all(configs[4] * 1000);
}

void sendHeartBeat( ) {
  loraAddTwoByteToBuffer(0x06, 0x03); // Uptime
  loraAddWordToBuffer(millis()/1000/60/60/24);     
  loraAddTwoByteToBuffer(0x06, 0x01); // Temperature
  loraAddWordToBuffer((int16_t)(temperature*10)); 
  loraAddTwoByteToBuffer(0x06, 0x81); // rain
  loraAddWordToBuffer(flipCount); // count = 500 ml
  loraAddTwoByteToBuffer(0x12, voltage); // Battery
  loraAddWordToBuffer(uAs/3600);       
  }

bool readConfigFlash() {
  bool error= api.system.flash.get(0,(uint8_t *)configs,CONFIGSIZE*sizeof(uint32_t));
  if(configs[0]!=0xA5A5A5A5) {
    configs[0] = 0xA5A5A5A5;   // MAGIC 
    configs[1] = 1;                             // compatible to ESP32 System register       
    configs[2] = DEFAULT_HEARTBEAT;             // heartbeats as multiple of reports (default 4 = 1h,alternative 96 =1 d)
    configs[3] = DEFAULT_HEAVYRAIN;             // 1 flip every 120 s => 30 f/h = 15 l/h
    configs[4] = DEFAULT_INTERVAL;              // regular reporting in seconds (default 900 = 15 min)
    configs[5] = 100;                           // calibration of ntc     
    configs[6] = 0;            // id  
    configs[7] = 0;            // status         
    writeConfigFlash();
    return false;
  }
  return error;
}
 
void writeConfigFlash() {
  bool error= api.system.flash.set(0,(uint8_t *)configs,CONFIGSIZE*sizeof(uint32_t));
}

void readLoraKeys() {
  // OTAA Device EUI MSB first
  uint8_t node_device_eui[8] = OTAA_DEVEUI;
  // OTAA Application EUI MSB first
  uint8_t node_app_eui[8] = OTAA_APPEUI;
  // OTAA Application Key MSB first
  uint8_t node_app_key[16] = OTAA_APPKEY;
          
  api.lorawan.appeui.set(node_app_eui, 8);  
  api.lorawan.deui.set(node_device_eui, 8);
  api.lorawan.appkey.set(node_app_key, 16); 
}


// #####
// Lora Part
// #####
#define OTAA_BAND     (RAK_REGION_EU868)
#define OTAA_PERIOD   (20000)
#define FPORT           2
#define LORAWAN_BUFSIZE 50 

#define P2P_FREQUENCY   869525000
#define P2P_SF          12
#define P2P_BW          125
#define P2P_CR          1
#define P2P_TXPWR       22
#define P2P_PREAMPLE    8

#define BUILD_MONTH_IS_JAN (__DATE__[0] == 'J' && __DATE__[1] == 'a' && __DATE__[2] == 'n')
#define BUILD_MONTH_IS_FEB (__DATE__[0] == 'F')
#define BUILD_MONTH_IS_MAR (__DATE__[0] == 'M' && __DATE__[1] == 'a' && __DATE__[2] == 'r')
#define BUILD_MONTH_IS_APR (__DATE__[0] == 'A' && __DATE__[1] == 'p')
#define BUILD_MONTH_IS_MAY (__DATE__[0] == 'M' && __DATE__[1] == 'a' && __DATE__[2] == 'y')
#define BUILD_MONTH_IS_JUN (__DATE__[0] == 'J' && __DATE__[1] == 'u' && __DATE__[2] == 'n')
#define BUILD_MONTH_IS_JUL (__DATE__[0] == 'J' && __DATE__[1] == 'u' && __DATE__[2] == 'l')
#define BUILD_MONTH_IS_AUG (__DATE__[0] == 'A' && __DATE__[1] == 'u')
#define BUILD_MONTH_IS_SEP (__DATE__[0] == 'S')
#define BUILD_MONTH_IS_OCT (__DATE__[0] == 'O')
#define BUILD_MONTH_IS_NOV (__DATE__[0] == 'N')
#define BUILD_MONTH_IS_DEC (__DATE__[0] == 'D')

#define COMPUTE_BUILD_MONTH \
    ( \
        (BUILD_MONTH_IS_JAN) ?  1 : \
        (BUILD_MONTH_IS_FEB) ?  2 : \
        (BUILD_MONTH_IS_MAR) ?  3 : \
        (BUILD_MONTH_IS_APR) ?  4 : \
        (BUILD_MONTH_IS_MAY) ?  5 : \
        (BUILD_MONTH_IS_JUN) ?  6 : \
        (BUILD_MONTH_IS_JUL) ?  7 : \
        (BUILD_MONTH_IS_AUG) ?  8 : \
        (BUILD_MONTH_IS_SEP) ?  9 : \
        (BUILD_MONTH_IS_OCT) ? 10 : \
        (BUILD_MONTH_IS_NOV) ? 11 : \
        (BUILD_MONTH_IS_DEC) ? 12 : \
        /* error default */  99 \
    )
    
uint8_t         ubitxbuffer[25];
int             joinbackoff=10;
uint32_t        lBufPtr;
uint8_t         lBuf[LORAWAN_BUFSIZE];


//######################################################################
// Setup
//######################################################################

void        loraSetup() {
  uint8_t retcode=0;
  lBufPtr = 0; 
  if (api.lorawan.nwm.get()==0 && (configs[7] & 0x01) == 0) 
     Serial.printf("Set Node device work mode to LoRaWAN %s\r\n", api.lorawan.nwm.set(1) ? "Success" : "Fail");
  if (api.lorawan.nwm.get() == 1) {
    Serial.printf("Start LoRaWAN Mode\n");
    readLoraKeys();  // fills appkey,deveui,appeui
    api.lorawan.band.set(OTAA_BAND);
    api.lorawan.registerJoinCallback(joinCallback);
    api.lorawan.deviceClass.set(RAK_LORA_CLASS_A);
    api.lorawan.njm.set(RAK_LORA_OTAA); 
    retcode = api.lorawan.njs.get();
    api.lorawan.join();
    while(!isLoRaWAN && retcode == 0 && millis() < 20000) {
      delay(1000);
      retcode = api.lorawan.njs.get();
    };  
    if(retcode == 0) { // will reboot !!!!
      configs[7] |= 1;      
      signal(false);
//      api.system.sleep.all(24*60*60 * 1000);
      writeConfigFlash();
      Serial.printf("No LoRaWAN,Switch over to Ubilink\n");
      api.lorawan.nwm.set(0);
      return; //never reached
    }
    else
       signal(true);   
  }
}

void        lorawanSend() {
  if (lBufPtr==0) return;
  #ifdef DEBUG
  Serial.print("LoraWAN TX ");
  for (int i = 0; i < lBufPtr; i++) Serial.printf("%02x ", lBuf[i]);
  Serial.print("\r\n");  
  #endif //DEBUG
  api.lorawan.send(lBufPtr, (uint8_t *) lBuf, FPORT);
}

void        lorawanReceiveCallback(SERVICE_LORA_RECEIVE_T * data) {
  if (data->BufferSize > 0) {
    Serial.print("LoraWan RX ");
    for (int i = 0; i < data->BufferSize; i++)  
      Serial.printf("%02x ", data->Buffer[i]);
    Serial.print("\r\n");
  }
  processCmd(data->Buffer, data->BufferSize);
}

void        lorawanSendCallback(int32_t status) {
  if (status != 0) {
    Serial.printf("TX Failed. Join status CB: %d/%d\r\n", status, api.lorawan.njs.get());
  }
  loraResetBuffer();
}

void        joinCallback(int32_t status) {
  Serial.printf("Join status CB: %d\r\n", status);
  if (status == 0) {
    api.lorawan.adr.set(true); //set ADR on
    api.lorawan.rety.set(3); //retry times
    api.lorawan.cfm.set(1);  // confirmation
    api.lorawan.registerRecvCallback(lorawanReceiveCallback);
    api.lorawan.registerSendCallback(lorawanSendCallback); 
    sendFwID();
    sendHwID();
    isLoRaWAN = true;
    signal(true);   
  } else {      
    isLoRaWAN = false;    
    signal(false); 
  }  
}


//######################################################################
// ASAP  
//######################################################################

void        processCmd(uint8_t * buf, int buflen) {
  int cidx=0;
  int bcmd;
  while (cidx < buflen) {
    bcmd = buf[10+cidx++];
    if (bcmd == 0x03) sendHwID();
    else if (bcmd == 0x0a) sendFwID();
    else if (bcmd == 0x04) {
      uint8_t p = buf[10+cidx++];
      loraAddTwoByteToBuffer(0x04, p); 
      loraAddWordToBuffer(configs[p]); 
      Serial.printf("ASAP Config #%d ?\n",p);
      } 
    else if (bcmd == 0x014) {
     uint8_t p = buf[cidx++];
     uint16_t v = (buf[10+cidx++]<<8) + buf[10+cidx++];
     configs[p] = v;
     Serial.printf("ASAP Config #%d : 0x%04x\n",p,v);
     writeConfigFlash();
    }
    else if (bcmd == 0x00) return;
  }
}

void        sendHwID() {
  loraAddTwoByteToBuffer(0x03, (byte)0x05);
  loraAddWordToBuffer(0x0001); //  capabilities    
  }

void        sendFwID() { 
  uint32_t fwVersion = getFWVersion(); 
  loraAddByteToBuffer(0x0A);
  loraAddWordToBuffer(fwVersion >> 16);
  loraAddWordToBuffer(fwVersion & 0xffff);
  }

void        sendHeavyRainAlarm(bool state,uint32_t val) { 
  loraAddByteToBuffer(0x0b);
  loraAddByteToBuffer(state);  
  loraAddByteToBuffer(0x03);    
  loraAddWordToBuffer(val/1000);
  if(isLoRaWAN) {api.lorawan.cfm.set(true);lorawanSend();} 
  }

uint32_t    getFWVersion() {
    String cs(__DATE__);
    return cs.substring(9,11).toInt()*10000+COMPUTE_BUILD_MONTH*100+cs.substring(4,6).toInt();  
}

bool        loraAddByteToBuffer(byte x) {
  if (lBufPtr == LORAWAN_BUFSIZE) return false;
  lBuf[lBufPtr]=x;
  lBufPtr++;
  return true;
}

bool        loraAddTwoByteToBuffer(byte x, byte y) {
  if (lBufPtr == LORAWAN_BUFSIZE) return false;
  lBuf[lBufPtr]=x;
  lBuf[lBufPtr+1]=y;
  lBufPtr +=2;
  return true;  
}

bool        loraAddWordToBuffer(uint16_t x) {
  if (lBufPtr == LORAWAN_BUFSIZE) return false;
  lBuf[lBufPtr]=x>>8;
  lBuf[lBufPtr+1]=x & 0xff;
  lBufPtr+=2;
  return true;
}

void        loraResetBuffer() {
  lBufPtr = 0;
  memset(lBuf,0x00,LORAWAN_BUFSIZE);   
}

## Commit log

2022-10-03 Initial Upload
    [RainMeterRAK.brd, RainMeterRAK.sch, RainMeterRAK.step]
2022-10-03 File Upload
    [RainMeterRAK.brd, RainMeterRAK.sch, RainMeterRAK.step]
2022-11-30 Update rain_ttn_decoder.js
    display some values as float, fix 2-complement display on temperature value, config values now in config array

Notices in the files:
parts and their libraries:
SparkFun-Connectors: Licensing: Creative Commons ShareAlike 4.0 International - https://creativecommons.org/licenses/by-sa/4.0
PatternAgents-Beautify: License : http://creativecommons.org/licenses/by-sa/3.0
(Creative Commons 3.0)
